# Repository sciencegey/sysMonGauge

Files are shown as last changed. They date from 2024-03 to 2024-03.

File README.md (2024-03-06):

# sysMonGauge
Fancy System Monitoring Gauge

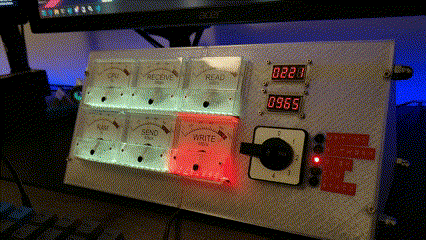
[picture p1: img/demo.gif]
Front profile view of the panel


## Building
The panel is designed to be printed using a standard FDM 3D printer (hence the funky split down the middle), but it would probably be better if you used a laser cutter or CNC router to cut the panel out of plastic or wood.

The rods were machined out of aluminium bar stock, but M8 threaded rod would work just as well.

I build the circuit on perf-board, but PCB files are included.

The dials were printed out onto self-adhesive paper and trimmed around the existing metal dials the gauges came with.

## Parts
<details>

<summary>Parts list</summary>

### Hardware
- 3x 360mm M8 threaded rod
- 12x M8 nuts
- 8x M3 hex-head screw (to attach the panel to the wings)
- 8x M2 hex-head screws and nuts (to attach the 7 segment displays)
- Lots of glue and zip-ties ;)
### Electronics
- 6x 5mA ammeter *"85C1"*
- 1x 5 position rotary switch *"LW26"*
- 2x 0.36" 4-digit 7 segment display *"TM1637"*
- 1M 144 LED WS2812B LED strip
- 6x 1k variable resistor
- 1x Raspberry Pi Pico
##
- 1x 330uF 16V electrolytic capacitor
- 5x 3mm red LED with holder
- 6x JST XH 1x2 connector
- 1x JST XH 1x5 connector
- 2x JST XH 1x4 connector
- 1x JST XH 1x6 connector
- 1x 2N7000 (TO-92)
- 2x 10k resistor
- 2x 470k resistor
</details>

## Installation
Open a command prompt as administrator and run `install.bat` to install the server as a Windows service, make sure the panel is plugged in, and it should spring to life!

Alternatively, to run the server standalone, make sure the service is stopped (`python sysMonSender.py stop`), then run `python sysMonSender.py debug` as an administrator.

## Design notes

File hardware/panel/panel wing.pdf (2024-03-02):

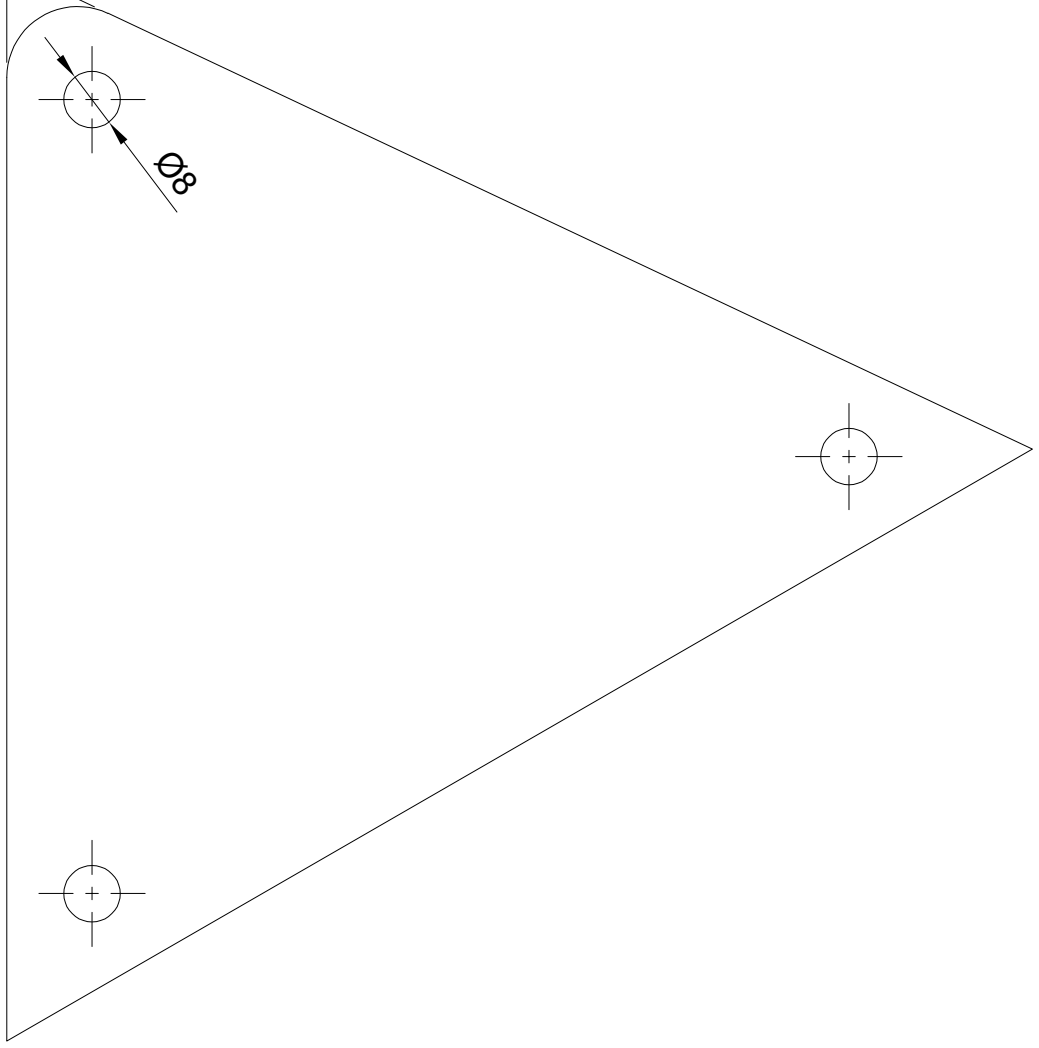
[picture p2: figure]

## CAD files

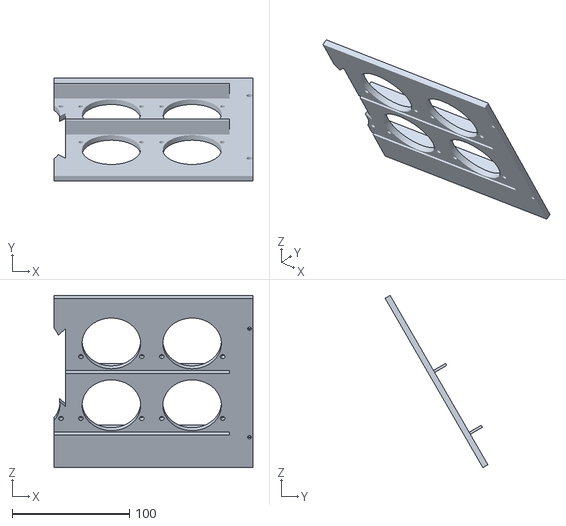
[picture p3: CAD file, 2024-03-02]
hardware/panel/3d print files/panelLeft.stl
170.0 x 87.8 x 147.1

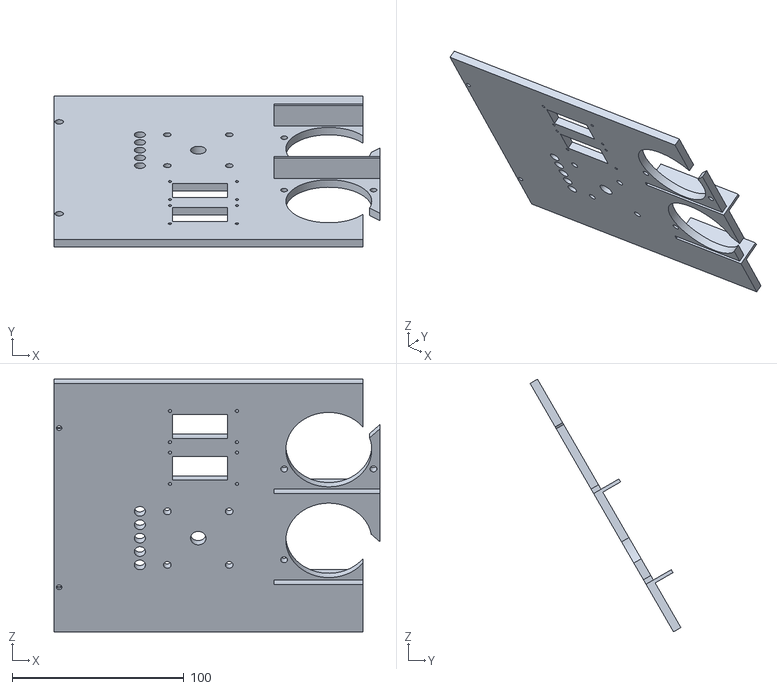
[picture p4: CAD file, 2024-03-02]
hardware/panel/3d print files/panelRight.stl
189.8 x 87.8 x 147.1

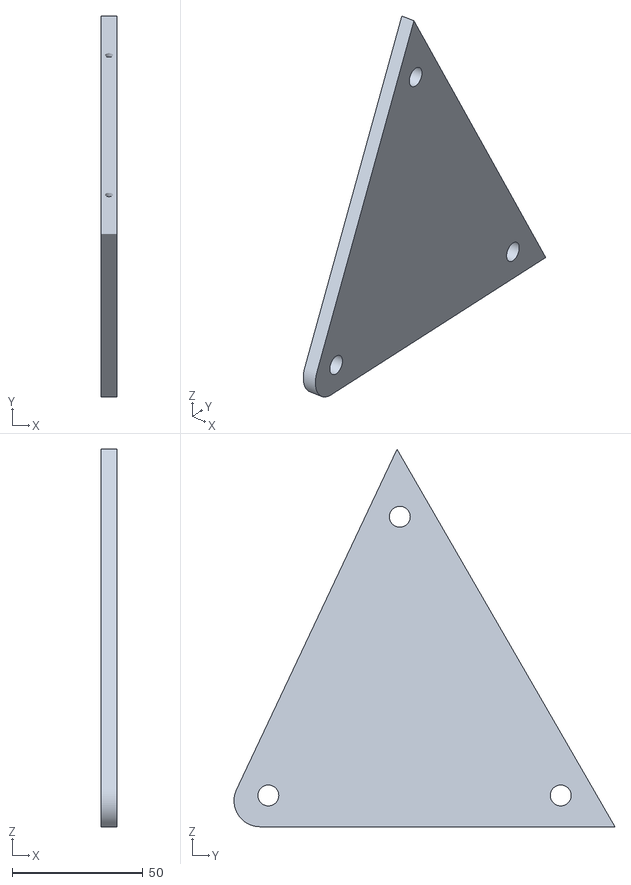
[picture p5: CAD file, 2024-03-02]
hardware/panel/3d print files/wing2.stl
6.00 x 145.9 x 144.6

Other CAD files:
hardware/panel/3d print files/wing1.stl
hardware/panel/cpu usage panel v51.f3z

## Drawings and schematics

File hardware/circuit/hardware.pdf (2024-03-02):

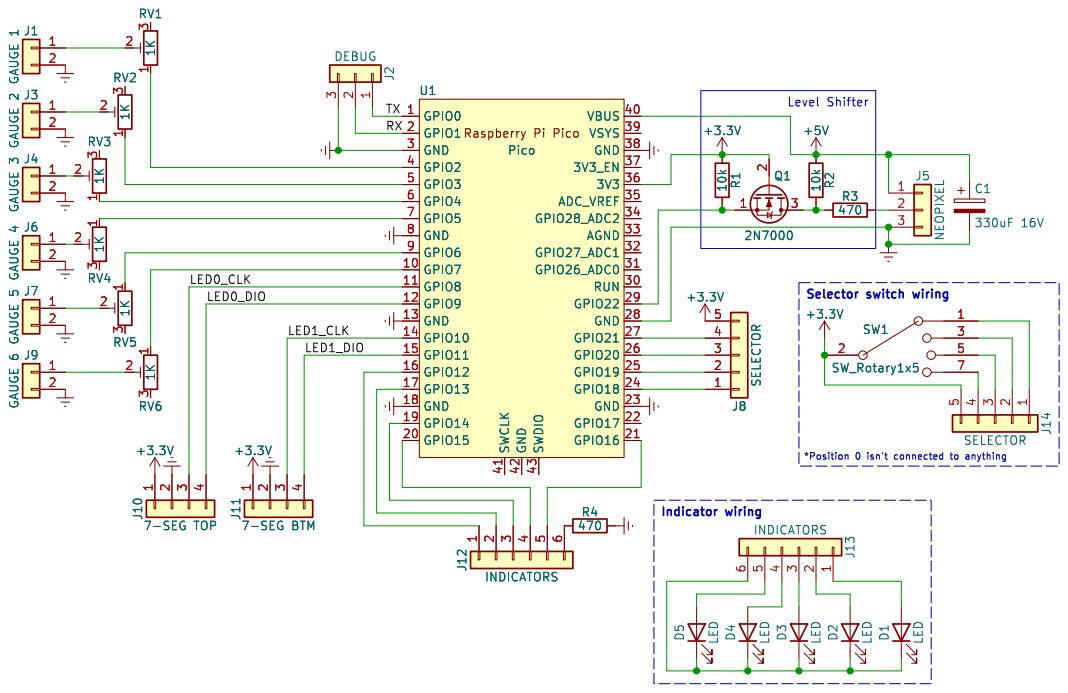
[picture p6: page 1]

3 U1 Pico GPIO0 1 GPIO7 10 GPIO8 11 GPIO9 12 GND 13 GPIO10 14 GPIO11 15 GPIO12 16 GPIO13 17 GND 18 GPIO14 19 GPIO1 2 GPIO15 20 GPIO16 21 GPIO17 22 GND 23 GPIO18 24 GPIO19 25 GPIO20 26 GPIO21 27 GND 28 GPIO22 29 GND 3 RUN 30 GPIO26_ADC0 31 GPIO27_ADC1 32 AGND 33 GPIO28_ADC2 34 ADC_VREF 35

Id: 1/1 Title: System Monitoring Panel File: hardware.kicad_sch Sheet: /

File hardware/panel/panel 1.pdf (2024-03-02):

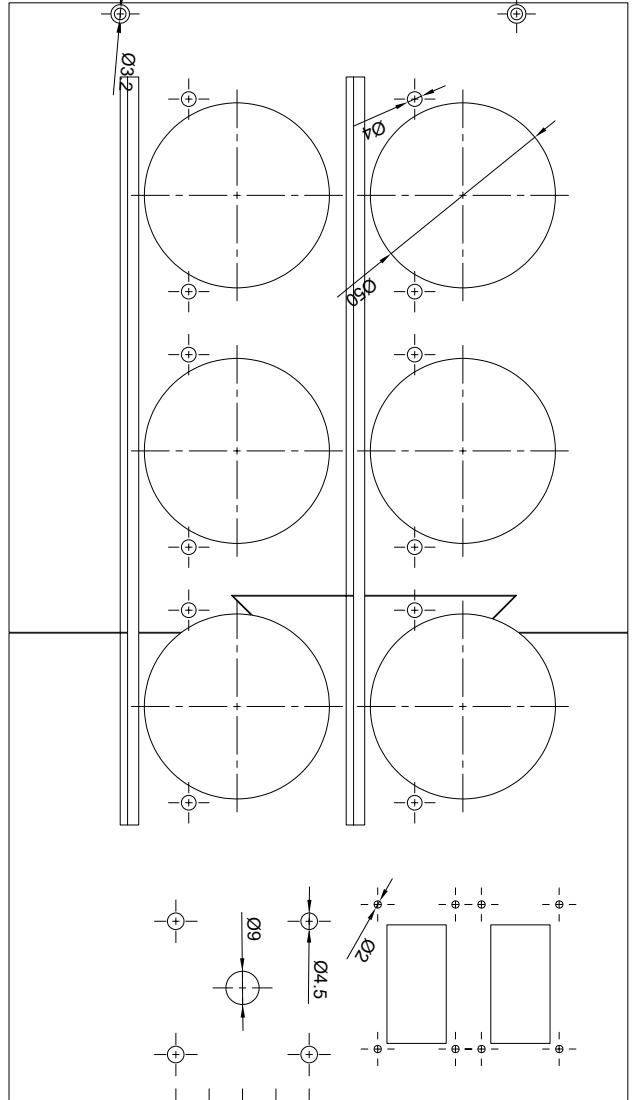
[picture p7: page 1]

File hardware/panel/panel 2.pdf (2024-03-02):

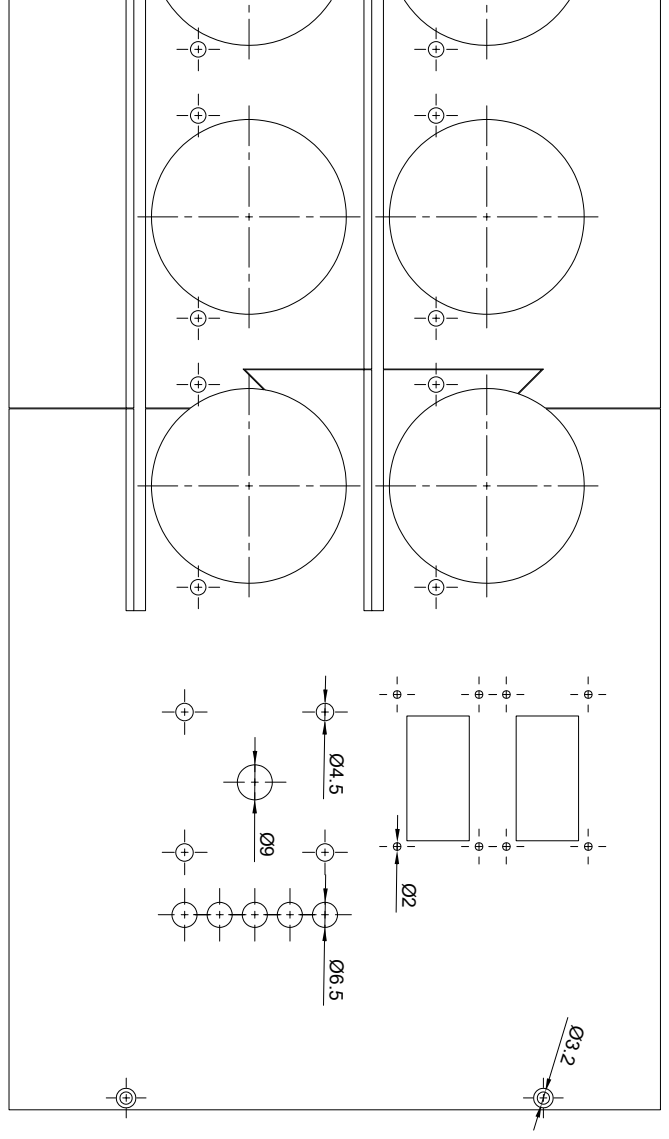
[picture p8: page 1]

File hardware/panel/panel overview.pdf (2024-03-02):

Ø12

Ø8

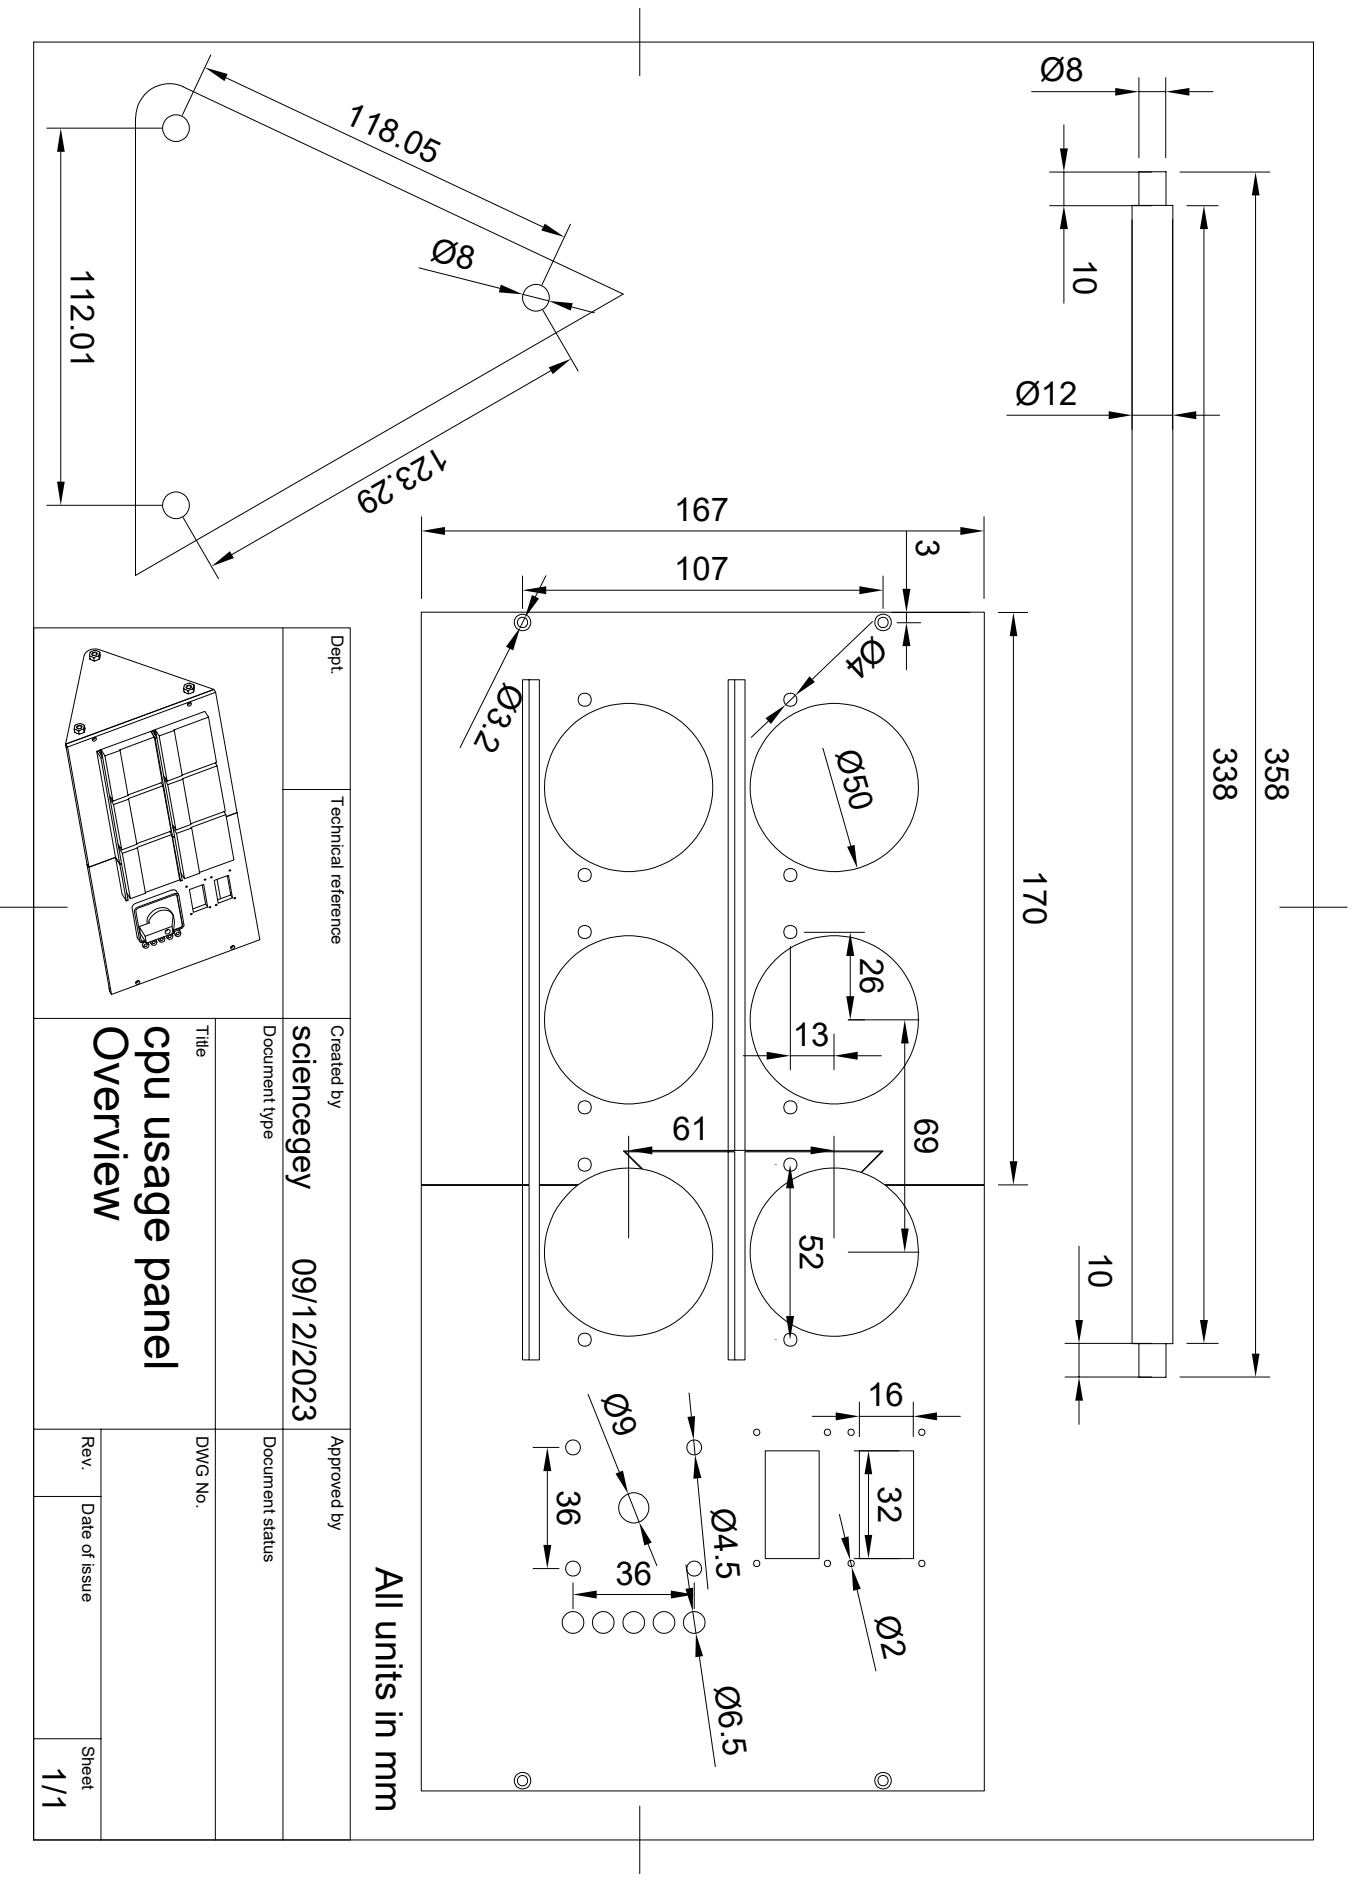
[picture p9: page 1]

Dept. Technical reference Created by Approved by Title DWG No. Document type Document status Rev. Date of issue Sheet 09/12/2023 1/1 Overview cpu usage panel sciencegey 338 10 10

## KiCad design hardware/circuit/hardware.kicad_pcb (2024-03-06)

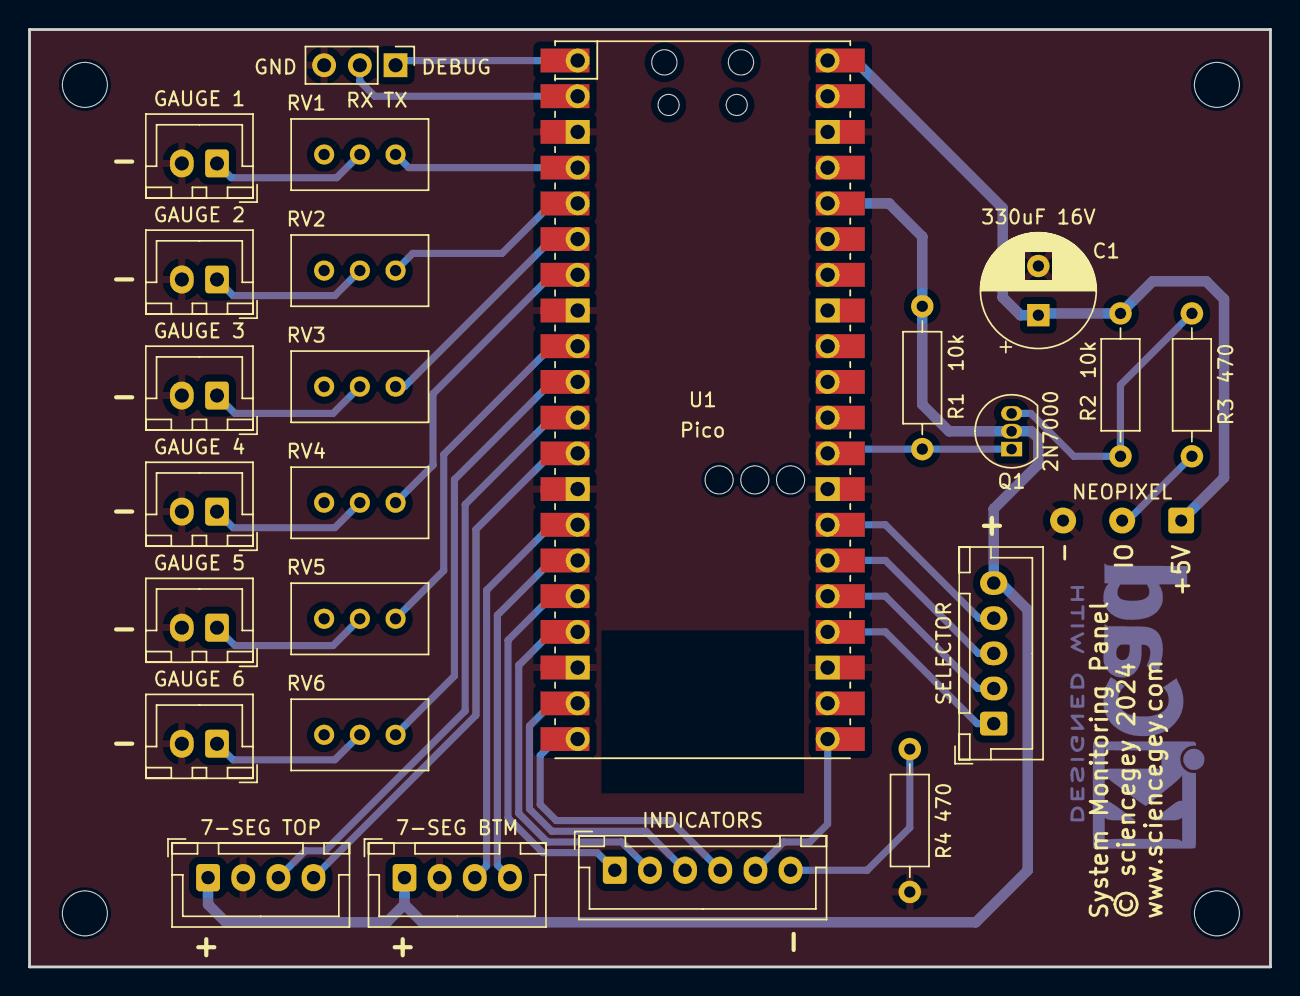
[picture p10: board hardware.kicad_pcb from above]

Board: 2 copper layers, 88.3 x 66.7 mm, 25 parts (0 on the bottom side), 34 nets.

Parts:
C1: 330uF 16V; CP_Radial_D8.0mm_P3.50mm
J1: GAUGE 1; JST_XH_B2B-XH-A_1x02_P2.50mm_Vertical
J2: DEBUG; PinHeader_1x03_P2.54mm_Vertical
J3: GAUGE 2; JST_XH_B2B-XH-A_1x02_P2.50mm_Vertical
J4: GAUGE 3; JST_XH_B2B-XH-A_1x02_P2.50mm_Vertical
J5: NEOPIXEL; SolderWire-0.25sqmm_1x03_P4.2mm_D0.65mm_OD1.7mm
J6: GAUGE 4; JST_XH_B2B-XH-A_1x02_P2.50mm_Vertical
J7: GAUGE 5; JST_XH_B2B-XH-A_1x02_P2.50mm_Vertical
J8: SELECTOR; JST_XH_B5B-XH-A_1x05_P2.50mm_Vertical
J9: GAUGE 6; JST_XH_B2B-XH-A_1x02_P2.50mm_Vertical
J10: 7-SEG TOP; JST_XH_B4B-XH-A_1x04_P2.50mm_Vertical
J11: 7-SEG BTM; JST_XH_B4B-XH-A_1x04_P2.50mm_Vertical
J12: INDICATORS; JST_XH_B6B-XH-A_1x06_P2.50mm_Vertical
Q1: 2N7000; TO-92_Inline
R1, R2: 10k; R_Axial_DIN0207_L6.3mm_D2.5mm_P10.16mm_Horizontal
R3, R4: 470; R_Axial_DIN0207_L6.3mm_D2.5mm_P10.16mm_Horizontal
RV1, RV2, RV3, RV4, RV5, RV6: 1K; Potentiometer_Bourns_3296W_Vertical
U1: Pico; RPi_Pico_W_SMD_TH

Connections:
+3.3V: J8.5, J10.1, J11.1, Q1.2 (G), R1.1, U1.36 (3V3)
+5V: C1.1, J5.1, R2.1, U1.40 (VBUS)
/LED0_CLK: J10.3, U1.11 (GPIO8)
/LED0_DIO: J10.4, U1.12 (GPIO9)
/LED1_CLK: J11.3, U1.14 (GPIO10)
/LED1_DIO: J11.4, U1.15 (GPIO11)
/RX: J2.2, U1.2 (GPIO1)
/TX: J2.1, U1.1 (GPIO0)
Earth: C1.2, J1.2, J2.3, J3.2, J4.2, J5.3, J6.2, J7.2, J9.2, J10.2, J11.2, R4.2, U1.3 (GND), U1.8 (GND), U1.13 (GND), U1.18 (GND), U1.23 (GND), U1.28 (GND), U1.38 (GND)
unnamed: J1.1, RV1.2
unnamed: J3.1, RV2.2
unnamed: J4.1, RV3.2
unnamed: J5.2, R3.2
unnamed: J6.1, RV4.2
unnamed: J7.1, RV5.2
unnamed: J8.1, U1.24 (GPIO18)
unnamed: J8.2, U1.25 (GPIO19)
unnamed: J8.3, U1.26 (GPIO20)
unnamed: J8.4, U1.27 (GPIO21)
unnamed: J9.1, RV6.2
unnamed: J12.1, U1.16 (GPIO12)
unnamed: J12.2, U1.17 (GPIO13)
unnamed: J12.3, U1.19 (GPIO14)
unnamed: J12.4, U1.20 (GPIO15)
unnamed: J12.5, U1.21 (GPIO16)
unnamed: J12.6, R4.1
unnamed: Q1.3 (D), R2.2, R3.1
unnamed: Q1.1 (S), R1.2, U1.29 (GPIO22)
unnamed: RV1.1, U1.4 (GPIO2)
unnamed: RV2.1, U1.5 (GPIO3)
unnamed: RV3.1, U1.6 (GPIO4)
unnamed: RV4.1, U1.7 (GPIO5)
unnamed: RV5.1, U1.9 (GPIO6)
unnamed: RV6.1, U1.10 (GPIO7)

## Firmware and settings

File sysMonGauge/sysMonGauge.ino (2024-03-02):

// MIT License
//
// Copyright (c) 2024 sciencegey
//
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
#define DEBUG false  //set to true for debug output, false for no debug output
#define DEBUG_SERIAL if(DEBUG)Serial1

#define CALIBRATE false // set to true to calibrate the dials

#include <Arduino.h>
#include <Wire.h>
#include <TM1637Display.h>

#include <Adafruit_NeoPixel.h>
#define PIN 22
#define NUMPIXELS 144
Adafruit_NeoPixel strip(NUMPIXELS, PIN, NEO_GRB + NEO_KHZ800);
#define BASECOL strip.Color(32, 32, 8) // Warm white
#define WARNCOL strip.Color(255, 255, 0)  // Yellow
#define ERRORCOL strip.Color(255, 0, 0) // Red

// Maps out which pixels correspond to which gauge (start, end)
const uint8_t pixelMap[][2] = {{0,9},{28,37},{19,28},{47,56},{37,47},{9,19}};
 
const uint8_t BUFFER_SIZE = 31;
// cpuUsage, ramUsage, diskRead, diskWrite, networkSent, networkRecv, diskUsage, systemUptime
char serBuf[BUFFER_SIZE];
char serBufLast[BUFFER_SIZE];
char diskUsage[16];

// Pins for the gauges
#define cpuUsagePin 2
#define ramUsagePin 3
#define diskReadPin  4
#define diskWritePin 5
#define networkSentPin 6
#define networkRecvPin 7

// Pins for the 7 segment displays
#define LED0_CLK 8
#define LED0_DIO 9
#define LED1_CLK 10
#define LED1_DIO 11

// Pins used for the rotary switch
const uint8_t swPins[] = {18, 19, 20, 21};
// 0 = clock, 1 = network send/receive, 2 = disk read/write, 3 = cpu speed, 4 = disk usage
uint8_t swPos = 0;
// Pins used for the LED indicators
const uint8_t ledPins[] = {12, 13, 14, 15, 16};

TM1637Display display0(LED0_CLK,LED0_DIO);
TM1637Display display1(LED1_CLK,LED1_DIO);

uint32_t systemUptimeBuf = 0;
uint32_t systemUptime = 0;
uint32_t diskReadRaw = 0;
uint32_t diskWriteRaw = 0;
uint32_t networkSentRaw = 0;
uint32_t networkRecvRaw = 0;
uint16_t cpuCurrentHz = 0;
uint16_t cpuMaxHz = 0;

// How many milliseconds between the page changing
#define refresh 2000

// What page we're on for pages that scroll
uint8_t page = 0;

uint8_t timeBuffer[4] = {0,0,0,0};
uint16_t displayBuffer = 0;

uint8_t numDisks = 0;

uint32_t then = millis();

void setup() {
  Serial.begin(115200);
  DEBUG_SERIAL.setTX(0);
  DEBUG_SERIAL.setRX(1);
  DEBUG_SERIAL.begin(115200);
  DEBUG_SERIAL.println("Starting!");
  pinMode(LED_BUILTIN, OUTPUT);

  // Setup the pins for each gauge as an output
  pinMode(cpuUsagePin, OUTPUT);
  pinMode(ramUsagePin, OUTPUT);
  pinMode(diskReadPin, OUTPUT);
  pinMode(diskWritePin, OUTPUT);
  pinMode(networkSentPin, OUTPUT);
  pinMode(networkRecvPin, OUTPUT);

  // Setup the pins for the input switch
  for(uint8_t i=0;i<(sizeof(swPins)/sizeof(swPins[0]));i++){
    pinMode(swPins[i], INPUT_PULLUP);
  }
  // Setup the pins for the LED indicators
  for(uint8_t i=0;i<(sizeof(ledPins)/sizeof(ledPins[0]));i++){
    pinMode(ledPins[i], OUTPUT);
  }

  // Brightness between 0 and 255
  display0.setBrightness(128);
  display1.setBrightness(128);
  display0.clear();
  display1.clear();

  strip.begin();
  strip.show();
  // Brightness between 0 and 255
  strip.setBrightness(50);
  // Set each pixel with a small delay so it ~looks cool~
  for(int i=0; i<NUMPIXELS; i++) {
    // pixels.Color() takes RGB values, from 0,0,0 up to 255,255,255
    // Here we're using a colour that's equivilent to a old light
    strip.setPixelColor(i, BASECOL);
    strip.show();   // Send the updated pixel colors to the hardware.
    delay(15); // Pause before next pass through loop
  }

  // Copy the new data into the last buffer so we can compare it to the next time around.
  memcpy(serBufLast, serBuf, sizeof(serBuf[0])*BUFFER_SIZE);

  DEBUG_SERIAL.println("Ready!");

  while (CALIBRATE) {
    // To calibrate the dials, make sure the dials are zeroed, then set CALIBRATE to true
    // Then adjust the variable resistors so the needles line up with 100/1000
    // Then set calibrate to false and reupload the sketch

    for(int i=0; i<NUMPIXELS; i++) {
      // pixels.Color() takes RGB values, from 0,0,0 up to 255,255,255
      // Here we're using a colour that's equivilent to a old light
      strip.setPixelColor(i, strip.Color(0, 0, 32));
      strip.show();   // Send the updated pixel colors to the hardware.
    }
    
    DEBUG_SERIAL.println("Calibrating dials");

    analogWrite(cpuUsagePin, 255);
    analogWrite(ramUsagePin, 255);
    analogWrite(diskReadPin, 255);
    analogWrite(diskWritePin, 255);
    analogWrite(networkSentPin, 255);
    analogWrite(networkRecvPin, 255);
  }
}

void loop() {
  // Get the system stats over serial
  if(Serial.available() > 0) {
    Serial.readBytes(serBuf, BUFFER_SIZE);

    // DEBUG_SERIAL.print("Got data: ");
    // for(int i = 0; i < BUFFER_SIZE; i++) {
    //   DEBUG_SERIAL.print(serBuf[i], DEC);
    //   DEBUG_SERIAL.print(" ");
    // }
    // DEBUG_SERIAL.println(swPos);

    digitalWrite(LED_BUILTIN, HIGH);
    delay(5);
    digitalWrite(LED_BUILTIN, LOW);
    delay(5);
  }

  if(memcmp(serBufLast, serBuf, sizeof(serBufLast[0]) * BUFFER_SIZE) != 0) {
    // Only update the displays if we have any new data
    // Copy the new data into the last buffer so we can compare it to the next time around.
    memcpy(serBufLast, serBuf, sizeof(serBuf[0])*BUFFER_SIZE);
    // DEBUG_SERIAL.println("New data!");


    // TODO : Smooth transition between values
    analogWrite(cpuUsagePin, int(serBuf[0]));
    analogWrite(ramUsagePin, int(serBuf[1]));
    analogWrite(diskReadPin, int(serBuf[2]));
    analogWrite(diskWritePin, int(serBuf[3]));
    analogWrite(networkSentPin, int(serBuf[4]));
    analogWrite(networkRecvPin, int(serBuf[5]));

    DEBUG_SERIAL.print("CPU: ");
    DEBUG_SERIAL.print(serBuf[0], DEC);
    DEBUG_SERIAL.print(" RAM: ");
    DEBUG_SERIAL.print(serBuf[1], DEC);
    DEBUG_SERIAL.print(" DISK READ: ");
    DEBUG_SERIAL.print(serBuf[2], DEC);
    DEBUG_SERIAL.print(" DISK WRITE: ");
    DEBUG_SERIAL.print(serBuf[3], DEC);
    DEBUG_SERIAL.print(" NET SEND: ");
    DEBUG_SERIAL.print(serBuf[4], DEC);
    DEBUG_SERIAL.print(" NET RECV: ");
    DEBUG_SERIAL.println(serBuf[5], DEC);


    // analogWrite(cpuUsagePin, 255);
    // analogWrite(ramUsagePin, 255);
    // analogWrite(diskReadPin, 255);
    // analogWrite(diskWritePin, 255);
    // analogWrite(networkSentPin, 255);
    // analogWrite(networkRecvPin, 255);

    for(uint8_t i=0; i<=6; i++){
      if(int(serBuf[i]) >=204){
        // Critical!
        for(uint8_t j=pixelMap[i][0]; j<pixelMap[i][1]; j++){
          strip.setPixelColor(j, ERRORCOL);
        }
      } else if(int(serBuf[i]) >=153){
        // Warning!
        for(uint8_t j=pixelMap[i][0]; j<pixelMap[i][1]; j++){
          strip.setPixelColor(j, WARNCOL);
        }
      } else {
        // Normal :)
        for(uint8_t j=pixelMap[i][0]; j<pixelMap[i][1]; j++){
          strip.setPixelColor(j, BASECOL);
        }
      }
    }
    strip.show();   // Send the updated pixel colors to the hardware.

    // The system time is a 32 bit "long", so it comes in in 4 byte chunks
    systemUptimeBuf = serBuf[10] << 24 | serBuf[9] << 16 | serBuf[8] << 8 | serBuf[7];

    // DEBUG_SERIAL.print("System uptime: ");
    // DEBUG_SERIAL.print(serBuf[10], DEC);
    // DEBUG_SERIAL.print(serBuf[9], DEC);
    // DEBUG_SERIAL.print(serBuf[8], DEC);
    // DEBUG_SERIAL.println(serBuf[7], DEC);

    // Same for these ones
    diskReadRaw = serBuf[14] << 24 | serBuf[13] << 16 | serBuf[12] << 8 | serBuf[11];
    diskWriteRaw = serBuf[18] << 24 | serBuf[17] << 16 | serBuf[16] << 8 | serBuf[15];
    networkSentRaw = serBuf[22] << 24 | serBuf[21] << 16 | serBuf[20] << 8 | serBuf[19];
    networkRecvRaw = serBuf[26] << 24 | serBuf[25] << 16 | serBuf[24] << 8 | serBuf[23];

    // But these are "short"s, so they're only 2 bytes
    cpuCurrentHz = serBuf[28] << 8 | serBuf[27];
    cpuMaxHz = serBuf[30] << 8 | serBuf[29];

    // Arrays start at zero, but disks don't ;)
    numDisks = int(serBuf[31])-1;

    // Get the current position of the selector switch
    getSwitchPos(swPos);
    //DEBUG_SERIAL.println("Switch Position: " + String(swPos));

    // Set the indicators for whichever page we're on
    for(uint8_t i=0;i<(sizeof(ledPins)/sizeof(ledPins[0]));i++){
      digitalWrite(ledPins[i], LOW);
    }
    digitalWrite(ledPins[swPos], HIGH);

    // Get the current millis
    uint32_t now = millis();

    if (swPos == 0){
      // System Uptime
      if(systemUptime < systemUptimeBuf){
        // Only update the display if the system time has actually changed (and systemtime is selected)
        //DEBUG_SERIAL.println("It's time to update");
        systemUptime = systemUptimeBuf;
        secondsToHMS(systemUptime, timeBuffer);

        // Display the minutes and seconds
        displayBuffer = 100*timeBuffer[2]+timeBuffer[3];
        //DEBUG_SERIAL.println("Minutes and seconds: " + String(displayBuffer));
        display1.showNumberDecEx(displayBuffer, 0b01000000, true);  // Print with the dots in the middle

        // Then display the days and hours
        displayBuffer = 100*timeBuffer[0]+timeBuffer[1];
        //DEBUG_SERIAL.println("Days and hours: " + String(displayBuffer));
        display0.showNumberDecEx(displayBuffer, 0b01000000, true);  // Print with the dots in the middle
      }
    } else if (swPos == 1){
      // Network sent/received
      // Show it in megabits a second
      display0.showNumberDec(networkSentRaw, true);
      display1.showNumberDec(networkRecvRaw, true);
    } else if (swPos == 2){
      // Disk read/write
      // Show it in megabytes a second
      display0.showNumberDec(diskReadRaw, true);
      display1.showNumberDec(diskWriteRaw, true);
    } else if (swPos == 3){
      // CPU speed
      display0.showNumberDec(cpuCurrentHz, true);
      display1.showNumberDec(cpuMaxHz, true);
    } else if (swPos == 4){
      // // Disk space usage
      // // Cycle through the pages
      // if(now - then >= refresh){
      //   then = now;
      //   page++;
      //   if(page > numDisks){
      //     page = 0;
      //   }
      // }
      // // Drive indicator doesn't need leading zeros
      // display0.showNumberDec(page, false);
      // // Convert the 0-255 value into a 0-100 (percentage) value
      // display1.showNumberDec(int(map(serBuf[31+page],0,255,0,100)), false);
    }
  }
}

void secondsToHMS(const uint32_t seconds, uint8_t *outBuf) {
  uint32_t t = seconds;
  uint8_t s = 0;
  uint8_t m = 0;
  uint8_t h = 0;
  uint8_t d = 0;
  
  s = t % 60; // First calculate seconds by moduloing by 60 (seconds in a minute)

  t = (t - s)/60; // Then subtract the seconds we've already accounted for, then divide by 60
  m = t % 60; // And do the same to calculate minutes (60 minutes in an hour)

  t = (t - m)/60; // Do the same as before
  h = t % 24; // But this time modulo by 24 (hours in a day)

  t = (t - h)/24; // And finally we're left with just the days
  d = t;

  // DEBUG_SERIAL.print("Days: ");
  // DEBUG_SERIAL.print(d);
  // DEBUG_SERIAL.print(" Hours: ");
  // DEBUG_SERIAL.print(h);
  // DEBUG_SERIAL.print(" Minutes: ");
  // DEBUG_SERIAL.print(m);
  // DEBUG_SERIAL.print(" Seconds: ");
  // DEBUG_SERIAL.println(s);
  outBuf[0] = d;
  outBuf[1] = h;
  outBuf[2] = m;
  outBuf[3] = s;
}

void getSwitchPos(uint8_t& swPos){
  // If none of the pins are activated, then the switch is "off" (0)
  swPos = 0;

  // Get the input of each pin, and return when we hit the first pin to be set
  for(uint8_t i=0;i<4;i++){
    if(digitalRead(swPins[i]) == LOW){
      swPos = i+1;
      return;
    }
  }
  return;
}

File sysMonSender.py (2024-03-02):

#!/usr/bin/env python3

# MIT License
# 
# Copyright (c) 2024 sciencegey
# 
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
import sys
import os

import win32serviceutil
import win32service
import win32event
import servicemanager
import socket

class sysMonSvc(win32serviceutil.ServiceFramework):
    _svc_name_ = "sysMonSender"
    _svc_display_name_ = "SysMon Gauge Sender"
    _svc_description_ = "Sender server for System Monitor Gauges"

    def __init__(self, args):
        win32serviceutil.ServiceFramework.__init__(self, args)
        self.hWaitStop = win32event.CreateEvent(None, 0, 0, None)
        socket.setdefaulttimeout(60)
        self.stopFlag = False

    def SvcStop(self):
        self.ReportServiceStatus(win32service.SERVICE_STOP_PENDING)
        win32event.SetEvent(self.hWaitStop)
        self.stopFlag = True

    def SvcDoRun(self):
        servicemanager.LogMsg(servicemanager.EVENTLOG_INFORMATION_TYPE,
                              servicemanager.PYS_SERVICE_STARTED,
                              (self._svc_name_,''))
        self.main()

    def main(self):
        import psutil
        import time
        import math
        import serial, serial.serialutil, serial.tools.list_ports
        import struct
        
        serWait = True
        serPort = "COM1"
        while serWait:
            for port in list(serial.tools.list_ports.comports()):
                if port.vid == 0x2e8a and port.pid == 0x4826:
                    serPort = port.device
                    serWait = False
            
            time.sleep(5)

        ser = serial.Serial(port=serPort, baudrate=115200)
        diskPartitions = psutil.disk_partitions()

        for i in range(len(psutil.disk_partitions())):
            if os.name == 'nt' and psutil.disk_partitions()[i].fstype == '':
                diskPartitions.remove(psutil.disk_partitions()[i])

        diskReadLast = 0
        diskWriteLast = 0
        networkSentLast = 0
        networkRecvLast = 0

        # cpuUsage, ramUsage, diskUsage, diskRead, diskWrite, networkSent, networkRecv, systemUptime
        values = [0x00,0x00,0x00,0x00,0x00,0x00,0x00,0x00,0x00,0x00,0x00,0x00,0x00,0x00]

        def translateValue(inValue=0,inMin=0,inMax=100,outMin=0,outMax=255):
            oldValue = inValue
            oldMin = inMin
            oldMax = inMax
            newMin = outMin
            newMax = outMax
            
            newValue = (((oldValue - oldMin) * (newMax - newMin)) / (oldMax - oldMin)) + newMin
            
            if newValue > outMax:
                newValue = outMax
            
            return int(newValue)

        now = int(time.time())

        diskReadLast = psutil.disk_io_counters().read_bytes
        diskWriteLast = psutil.disk_io_counters().write_bytes
        networkSentLast = psutil.net_io_counters().bytes_sent
        networkRecvLast = psutil.net_io_counters().bytes_recv

        diskReadThen = time.time()
        diskWriteThen = time.time()
        networkSentThen = time.time()
        networkRecvThen = time.time()

        cpuUsage = 0
        ramUsage = 0
        cpuFreq = 0
        cpuFreqMax = 0
        diskRead = 0
        diskWrite = 0
        networkSent = 0
        networkRecv = 0
        diskUsage = [0]*len(diskPartitions)

        while not self.stopFlag:
            try:
                diskUsageTotal = 0   # Disk usage is cumulative, so we reset it to 0 on each run
                
                cpuUsage = psutil.cpu_percent(interval=0.25)    # Current CPU usage
                cpuFreq = psutil.cpu_freq().current  # On Linux gets the current CPU frequency, on everything else just returns the max
                cpuFreqMax = psutil.cpu_freq().max   # Max CPU frequency
                ramUsage = psutil.virtual_memory().percent  # Current physical memory usage
                for i in range(len(diskPartitions)):
                    diskUsage[i] = int(psutil.disk_usage(diskPartitions[i].mountpoint).percent)
                    diskUsageTotal += psutil.disk_usage(diskPartitions[i].mountpoint).percent                  

                # Get the bytes/second values from the counters
                diskRead = int(((psutil.disk_io_counters().read_bytes - diskReadLast)/1024/1024)/(time.time() - diskReadThen))
                diskReadLast = psutil.disk_io_counters().read_bytes
                diskReadThen = time.time()
                diskWrite = int(((psutil.disk_io_counters().write_bytes - diskWriteLast)/1024/1024)/(time.time() - diskWriteThen))
                diskWriteLast = psutil.disk_io_counters().write_bytes
                diskWriteThen = time.time()
                
                networkSent = int((((psutil.net_io_counters().bytes_sent - networkSentLast)/1024/1024)*8)/(time.time() - networkSentThen))
                networkSentLast = psutil.net_io_counters().bytes_sent
                networkSentThen = time.time()
                networkRecv = int((((psutil.net_io_counters().bytes_recv - networkRecvLast)/1024/1024)*8)/(time.time() - networkRecvThen))
                networkRecvLast = psutil.net_io_counters().bytes_recv
                networkRecvThen = time.time()
                systemUptime = int(time.time())-int(psutil.boot_time()) # Difference in time of system startup vs current time
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

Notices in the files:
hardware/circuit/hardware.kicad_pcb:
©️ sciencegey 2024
